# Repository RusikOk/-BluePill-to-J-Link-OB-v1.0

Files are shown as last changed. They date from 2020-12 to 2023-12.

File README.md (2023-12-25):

# programmer-BluePill-to-J-Link-OB-v1.0
успешная попытка создать программатор J-Link OB v1.0 на чипе CS32F103C8T6

в общем валялось у меня пару лет макетка с кристалом CS32F103. использовать в своих разработках я бы такое не стал. а в качестве J-Link OB они зашли на ура.

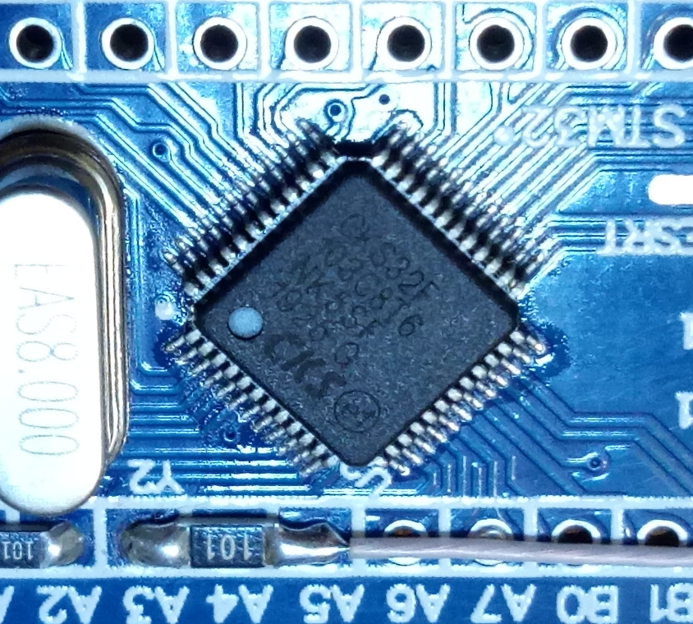
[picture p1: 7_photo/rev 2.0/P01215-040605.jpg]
какашка
 

<h2>REV 1.0</h2>

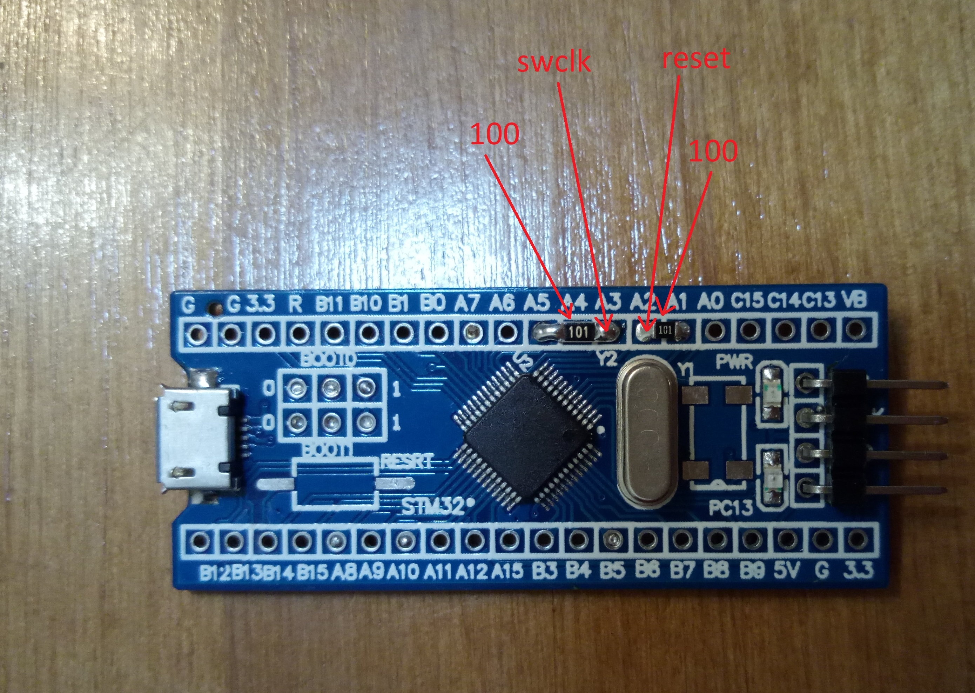
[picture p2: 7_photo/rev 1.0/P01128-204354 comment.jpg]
 
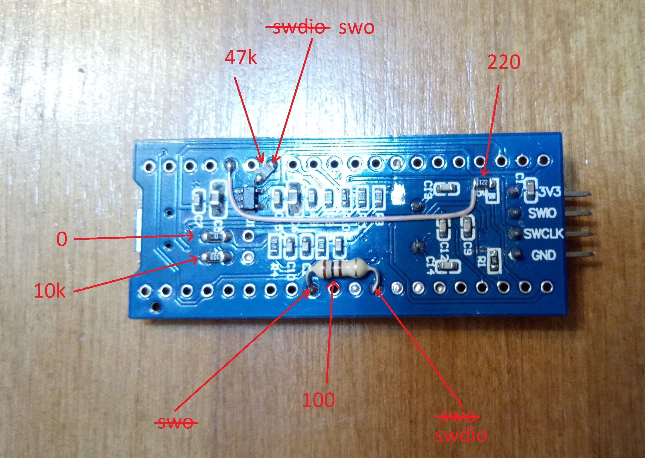
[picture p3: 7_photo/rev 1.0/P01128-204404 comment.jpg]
 
<br>
выявленные недостатки:<br>
- очень бесит когда при обновлении прошивки она тупо слетает в следствии использования мной МК на 64кБ. в идеале нужно использовать МК на 128кБ флешки. хотя если не шляться по чужим компам и постоянно не обновлять библиотеки jLink то жить можно.<br>
- маленькая нагрузочная способность встроенного в BluePill LDO всего на 300мА, что не позволяет запитывать target током больше 250мА.<br>
- при подключении target на горячую проседает питание программатора и он отваливается. приходится перетыкать USB.<br>
<br>
ссылки:<br>
<a href="http://forum.easyelectronics.ru/viewtopic.php?p=649897#p649897">J-Link OB (On-Board)</a><br>

<h2>REV 1.1</h2>

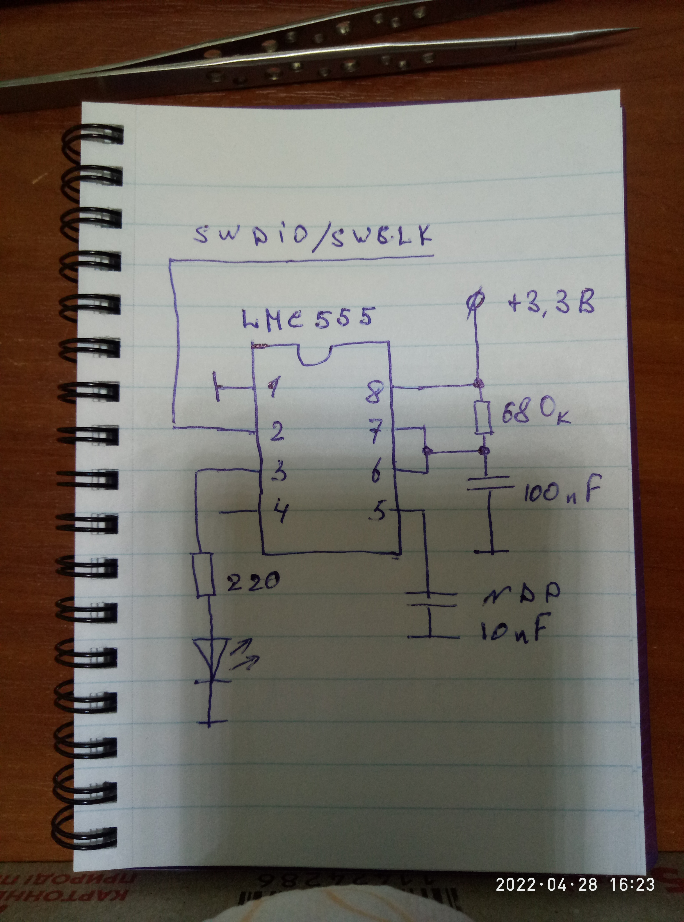
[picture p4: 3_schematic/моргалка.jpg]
schematic

bottom
выявленные недостатки:<br>
- вход таймера нужно было подключать к SW_DIO чтобы при отключенном target светодиод не моргал.<br>

<h2>REV 2.0</h2>

особенностью второй версии программатора является возможность запитки целевой платы током до 1А благодаря применению понижающего DC-DC преобразователя напряжения.<br>
<br>
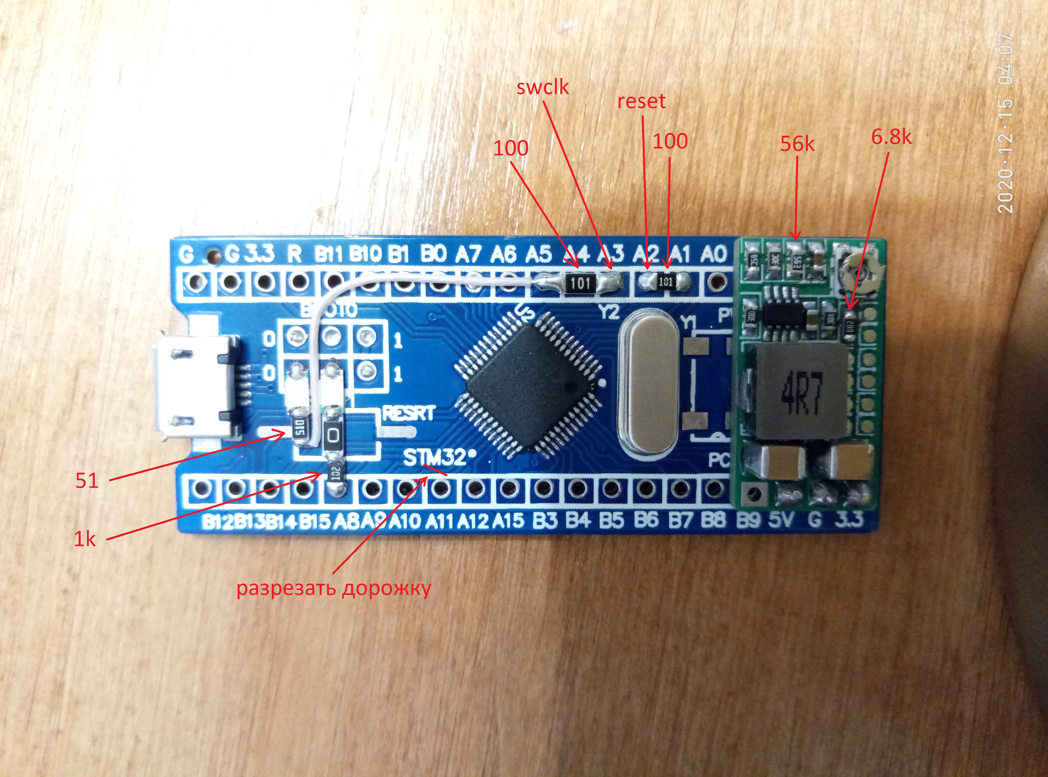
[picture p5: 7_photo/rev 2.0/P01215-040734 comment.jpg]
 
1) проверить все номиналы резисторов на DC-DC, китайцы могут вариировать номиналы<br>
2) не помню перерезана перемычка ADJ с обратной стороны DC-DC или нет. проверить<br>
3) на синий светодиод SW_CLK желательно поставить транзистор в ключевом режиме дабы по минимуму нагружать вывод МК<br>
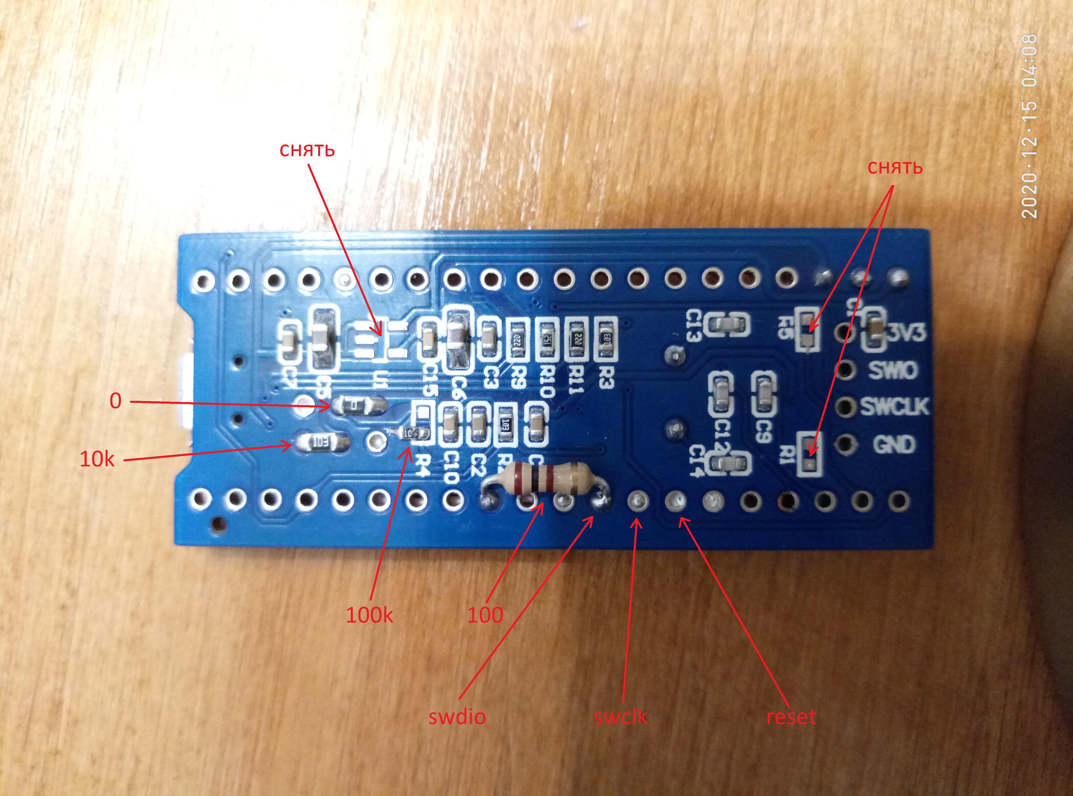
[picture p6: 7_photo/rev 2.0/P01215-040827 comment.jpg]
 
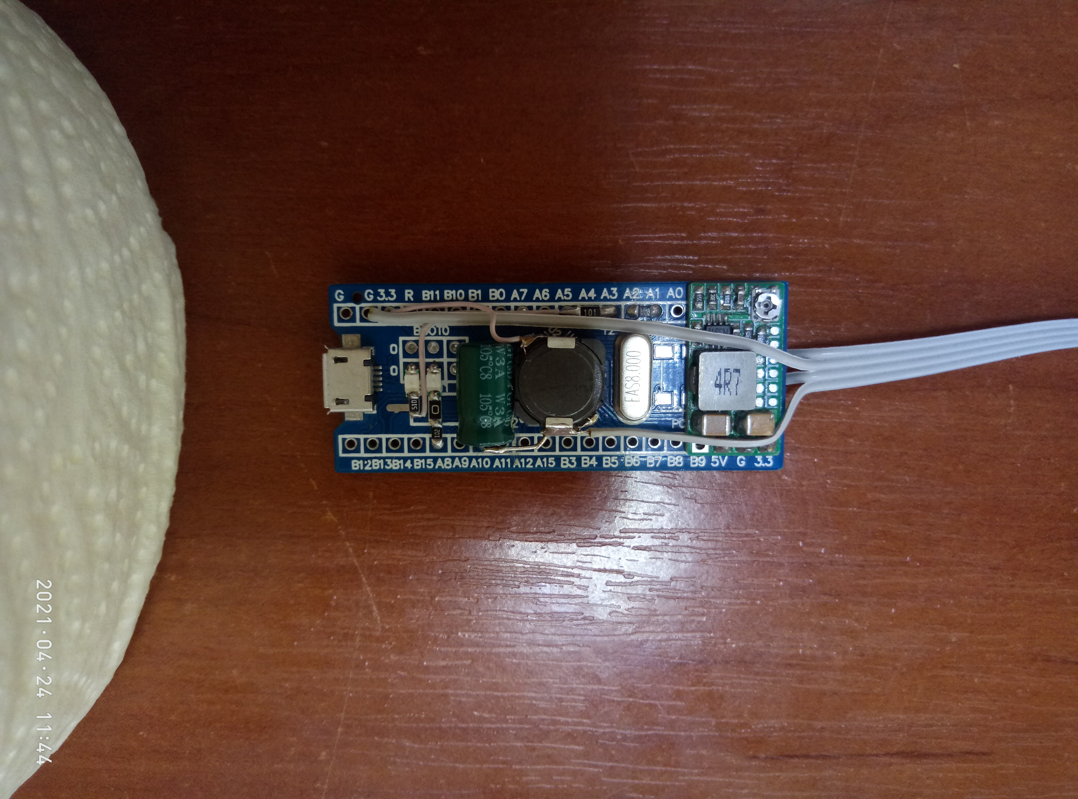
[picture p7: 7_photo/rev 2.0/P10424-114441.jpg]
 
bottom 
<br>
выявленные недостатки:<br>
- очень бесит когда при обновлении прошивки она тупо слетает в следствии использования мной МК на 64кБ. в идеале нужно использовать МК на 128кБ флешки. хотя если не шляться по чужим компам и постоянно не обновлять библиотеки jLink то жить можно.<br>
- оказалась неудачной компоновка светодиодов зеленый (USB) и синий (SW_CLK) сливаются в следствии чего через корпус не видно происходит обмен с target или нет. зеленый светодиод нужно оставить на месте возле разъема USB а синий перенести на противоположную сторону платы. возможно использовать DIP корпус диаметром 3мм.<br>
- на больших скоростях обмена синий светодиод (SW_CLK) очень слабо виден. поэтому как вариант поставить одновибратор на LMC555 таймере для выравнивания длительности свечения светодиода.<br>
<br>
ссылки:<br>
<a href="https://mysensors-rus.github.io/Blue-pill-to-JLink/">Делаем из BluePill пограмматор/отладчик JLink OB-STM32F103</a><br>
<a href="http://forum.easyelectronics.ru/viewtopic.php?p=650368#p650368">J-Link OB (On-Board)</a><br>
<a href="http://easyelectronics.ru/malenkaya-xitrost.html">Маленькая хитрость</a><br>
<a href="http://we.easyelectronics.ru/STM32/cs32f103c8t6-gd32f103cbt6-i-drugie-kitayskie-klony-stm32f103c8t6-i-stm32f030c8t6.html">китайские клоны STM32</a><br>

<h2>BOX</h2>

<a href="https://github.com/RusikOk/-BluePill-to-J-Link-OB-v1.0/blob/main/6_3D%20%D0%BF%D0%B5%D1%87%D0%B0%D1%82%D1%8C/for%20Dobot%20Mooz%202%20-%20PLA.curaprofile">настройки слайсера Ultimaker Cura для генерации G-кода для 3D принтера Dobot Mooz 2</a>

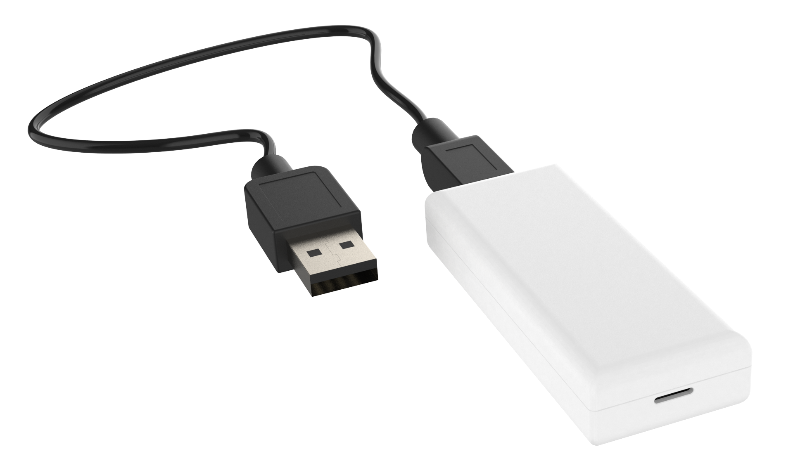
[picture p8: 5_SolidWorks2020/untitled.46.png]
 
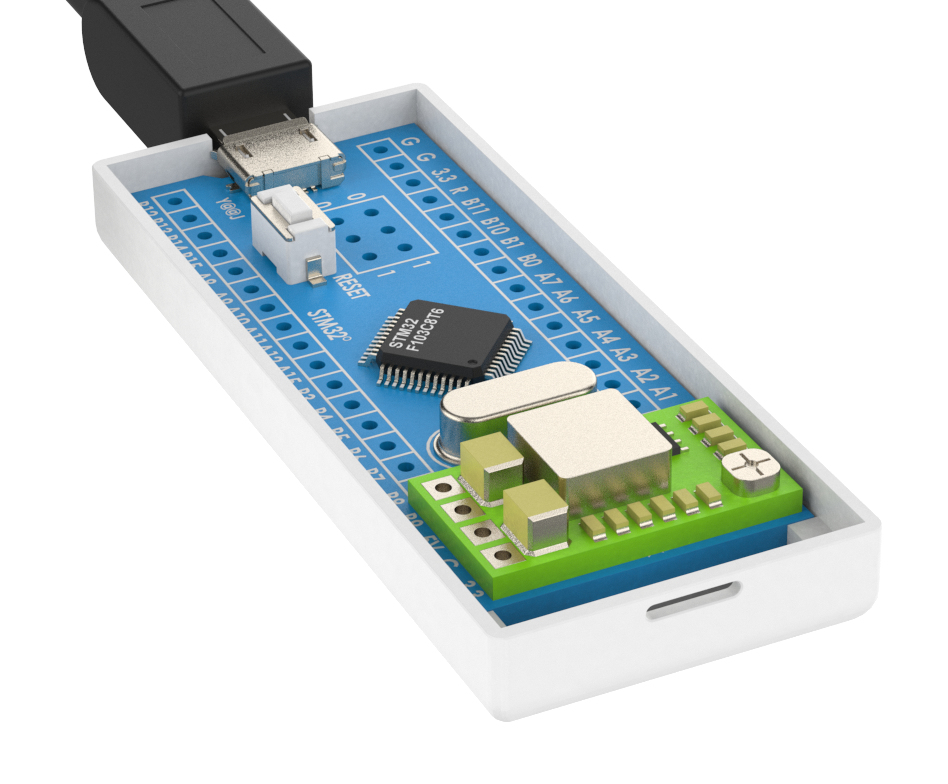
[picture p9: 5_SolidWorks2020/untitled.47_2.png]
 
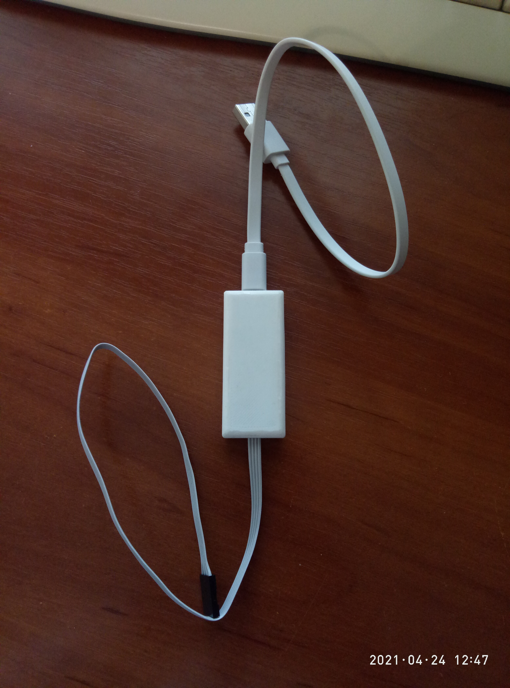
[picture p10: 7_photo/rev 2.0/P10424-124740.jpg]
 
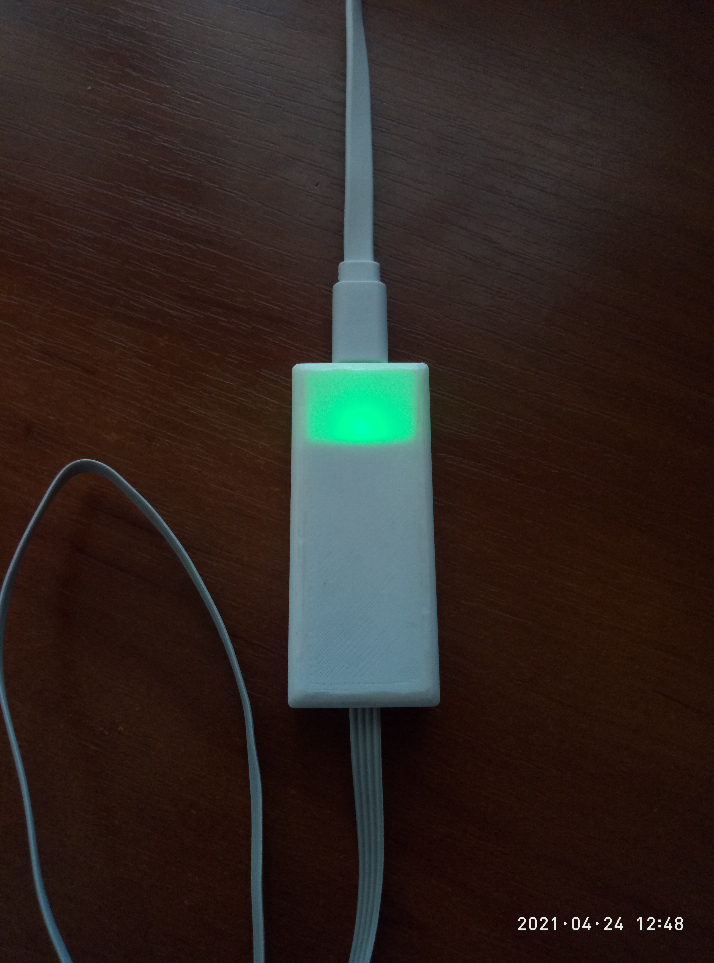
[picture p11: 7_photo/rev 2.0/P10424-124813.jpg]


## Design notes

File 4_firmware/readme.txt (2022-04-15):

последовательность прошивки самого программатора compiled Apr 8 2020 10:10:28 	(НЕ АКТУАЛЬНО)

1) зашить прошивку 1_2019_jlink-obSTM32F103.bin
2) запустить утилиту JLink.exe из старой версии драйверов c:\Program Files (x86)\SEGGER\JLink_V500\
3) установить новый серийный номер коммандой "exec SetSN=20201111"
4) зашить прошивку 2_JLink_OB_STM32F103_V1_compiled_Apr_8_2020.bin

(с) RusikOk 2020-11-29

последовательность прошивки новой версии программатора compiled Feb 2 2021 16:45:54

1) зашить прошивку 3_JLink_OB_STM32F103_V1_compiled Feb 2 2021.bin
2) запустить утилиту JLink.exe из старой версии драйверов c:\Program Files (x86)\SEGGER\JLink_V500\
3) установить новый серийный номер коммандой "exec SetSN=20211111"

(с) RusikOk 2021-04-21

последовательность создания новой версии прошивки программатора для МК CS32F103

1) зашить прошивку 4_JLOB103V1_bootloader.bin
2) подключаем J-Link к компьютеру по USB и запускаем J-Link Commander, а он уже установит актуальную версию прошивки
3) запустить утилиту JLink.exe из старой версии драйверов c:\Program Files (x86)\SEGGER\JLink_V500\
4) установить новый серийный номер коммандой "exec SetSN=20210420"

опять что-то поменялось(

1) зашиваем прошивку загрузчика 4_JLOB103V1_bootloader.hex в контроллер со 128кБ памяти
2) подключаем по USB
3) запускаем самую свежую версию JLink.exe, и обновляем прошивку
4) несколько раз отключаем программатор по USB и обратно включаем
5) подключаемся по SWD к контроллеру с полной прошивкой
6) вычитываем 64кБ (Size 0x10000) и сохраняем в файл
7) записываем с файла в CS32F103
8) копируем 8 байт с адреса 0x08004000 в буффер обмена и вставляем на адрес 0x08000000
9) устанавливать новый серийник ЗАПРЕЩЕНО!!! пусть остается -1
10) готовая прошивка от 2021-10-27 с названием 5_2021-10-27.hex

(с) RusikOk 2021-10-27

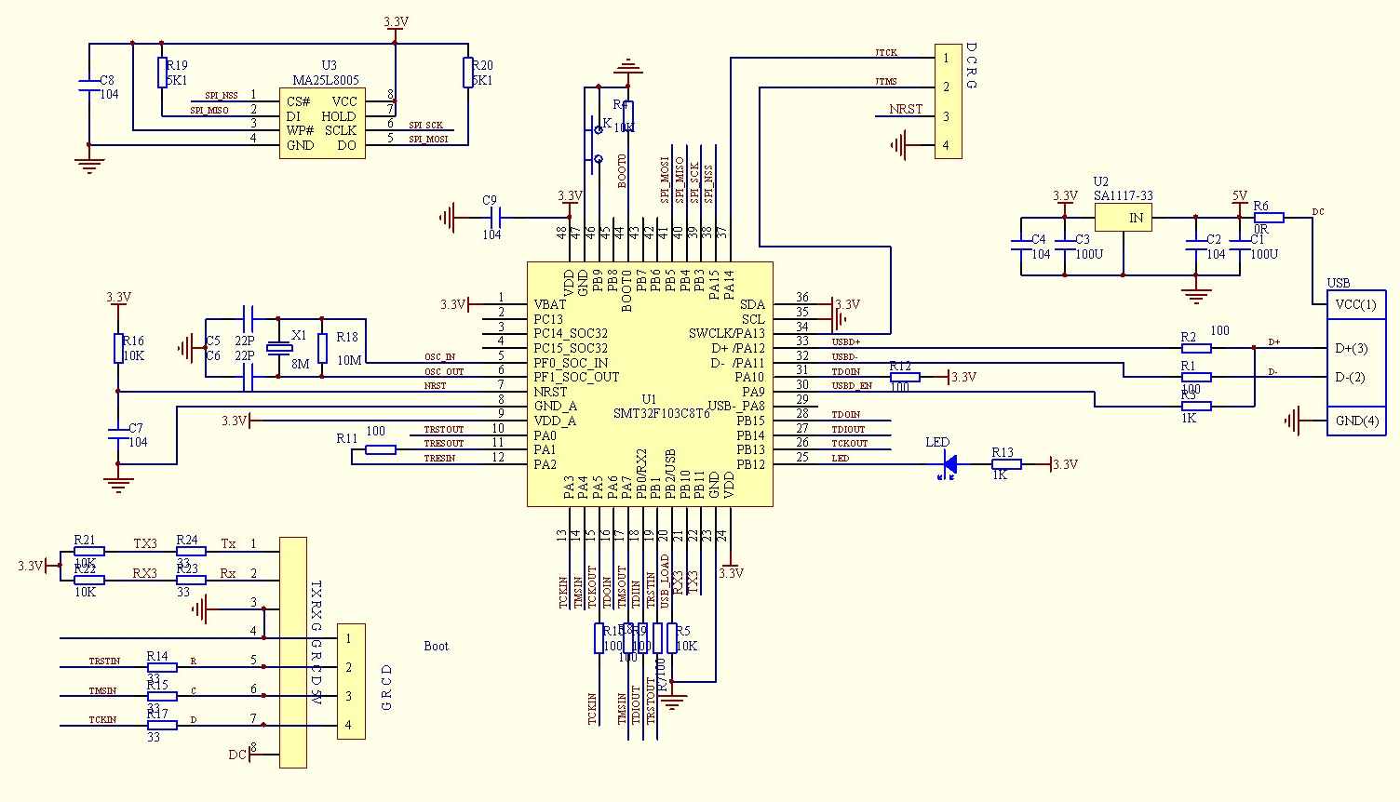
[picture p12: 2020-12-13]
3_schematic/2019_jlink-obSTM32F103_не правильная.jpg

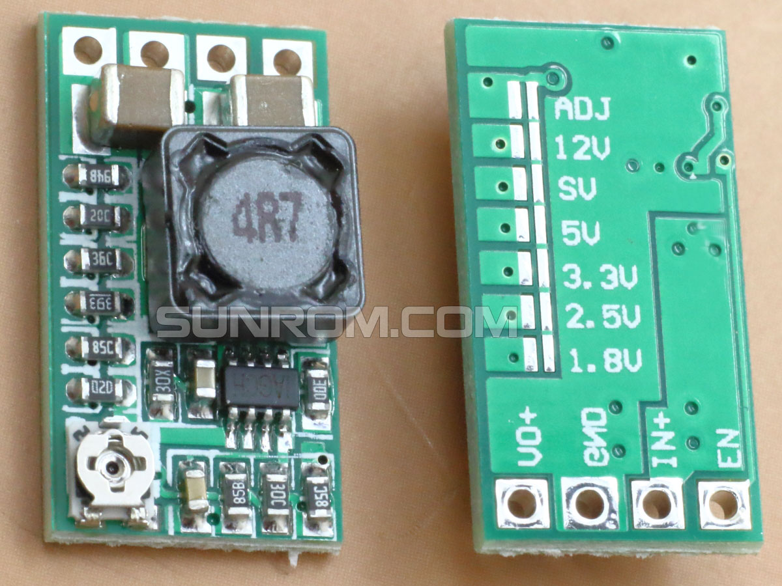
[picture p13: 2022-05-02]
2_datasheet/MP2315S.jpg

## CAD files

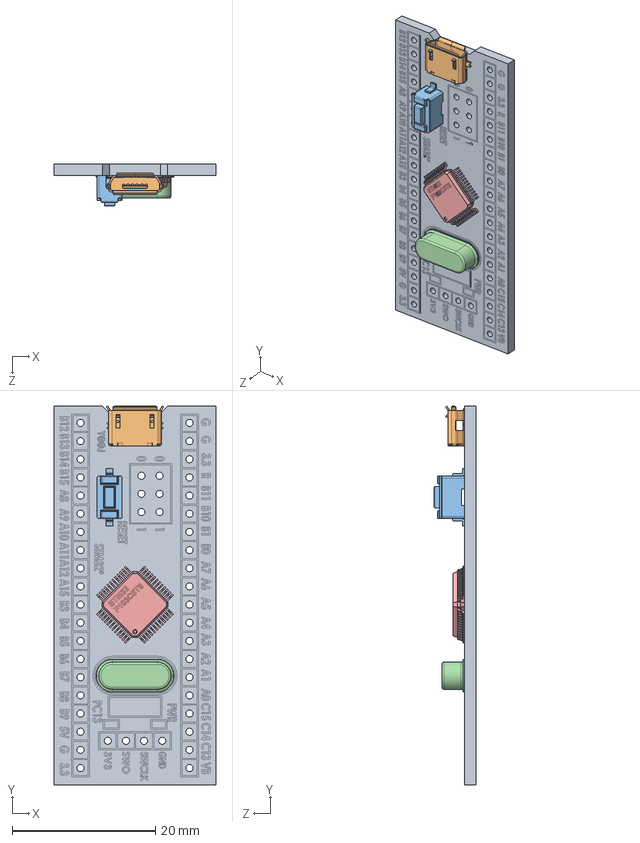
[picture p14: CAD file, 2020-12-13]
5_SolidWorks2020/2_BluePill/BluePill.SLDASM
22.6 x 53.0 x 5.90 mm
BluePill_Board
USB_Socket
Pushbutton
Quartz_1___ _________
STM32F103C8T6

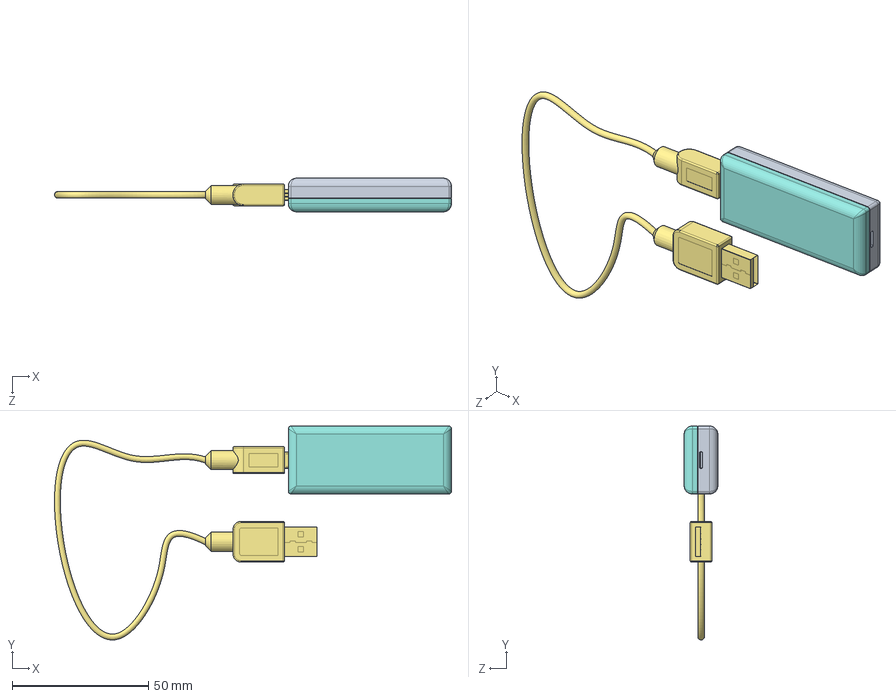
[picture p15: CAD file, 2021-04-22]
5_SolidWorks2020/Сборка.SLDASM
145.9 x 78.6 x 12.4 mm
основание
BluePill_Board
USB_Socket
Pushbutton
Quartz_1___ _________
STM32F103C8T6
microUSB_cabel
крышка
05KJ_Mini_PCB_Regulator
CDRH104RNP
Cap electro 6_3x11x2_5mm

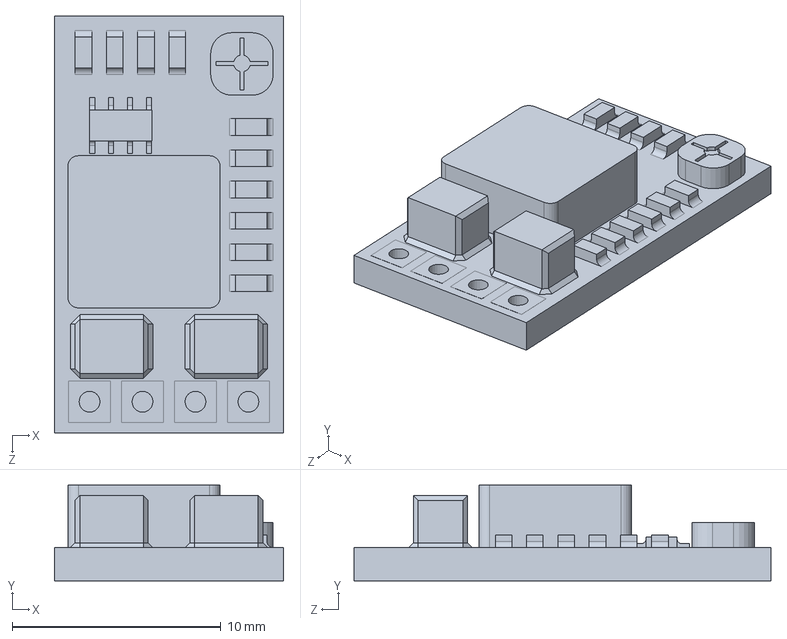
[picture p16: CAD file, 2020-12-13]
5_SolidWorks2020/step-down-converter-1.snapshot.5/05KJ_Mini_PCB_Regulator.SLDPRT
11.0 x 4.60 x 20.0 mm

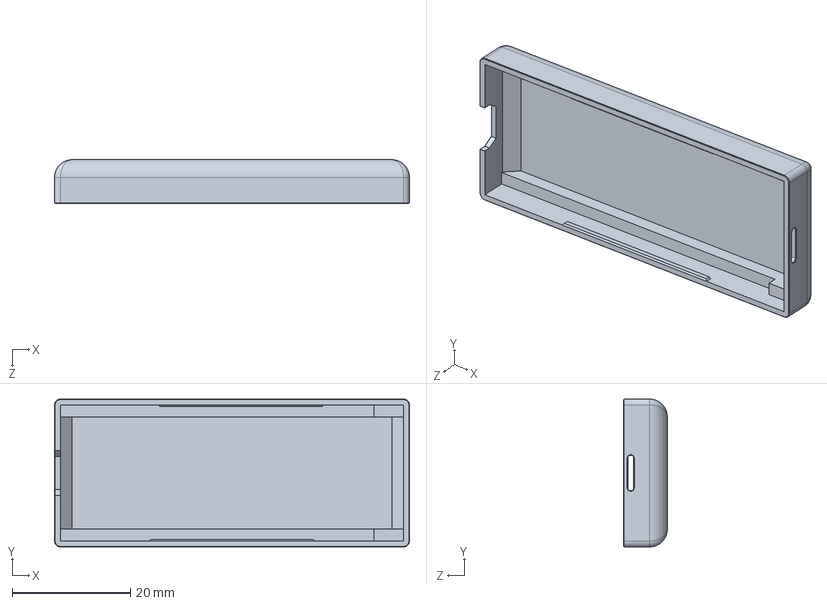
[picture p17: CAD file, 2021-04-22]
5_SolidWorks2020/основание.SLDPRT
60.0 x 25.0 x 7.40 mm

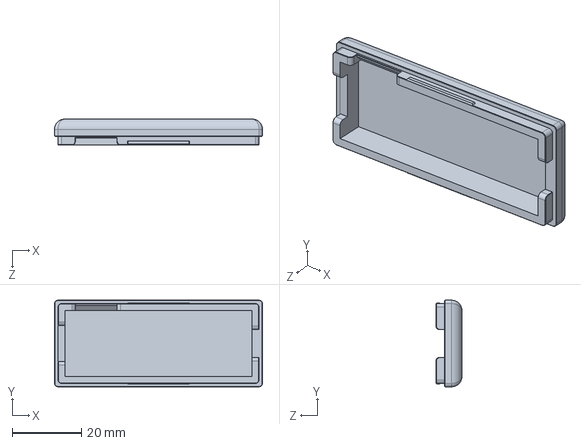
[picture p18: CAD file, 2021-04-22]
5_SolidWorks2020/крышка.SLDPRT
60.0 x 25.0 x 7.50 mm

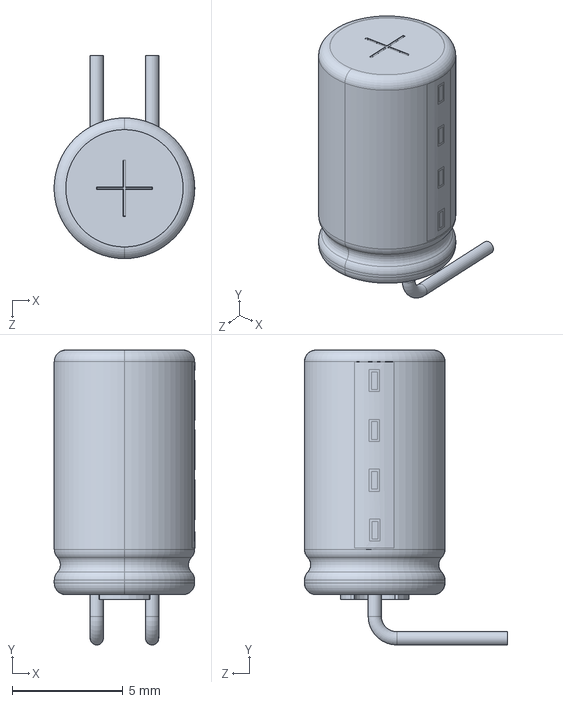
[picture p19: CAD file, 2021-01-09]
5_SolidWorks2020/Cap electro 6_3x11x2_5mm.sldprt
6.35 x 13.3 x 9.18 mm

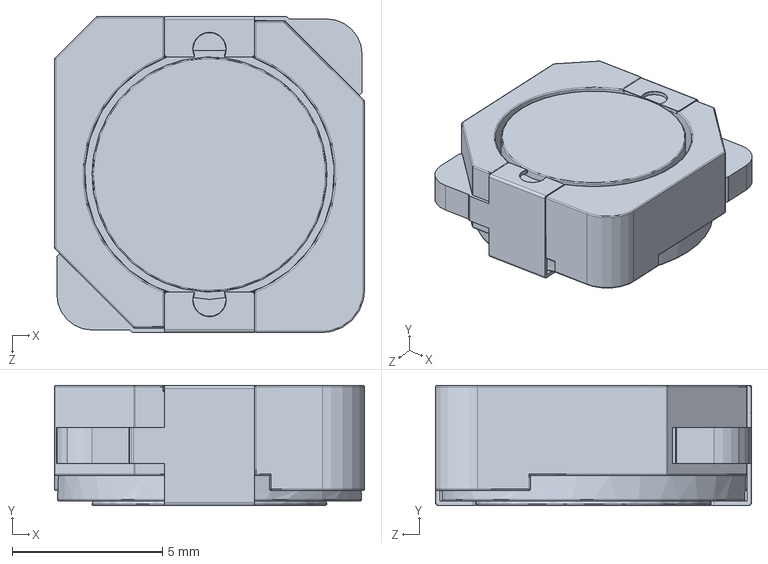
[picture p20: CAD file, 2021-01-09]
5_SolidWorks2020/CDRH104RNP.SLDPRT
10.3 x 4.00 x 10.5 mm

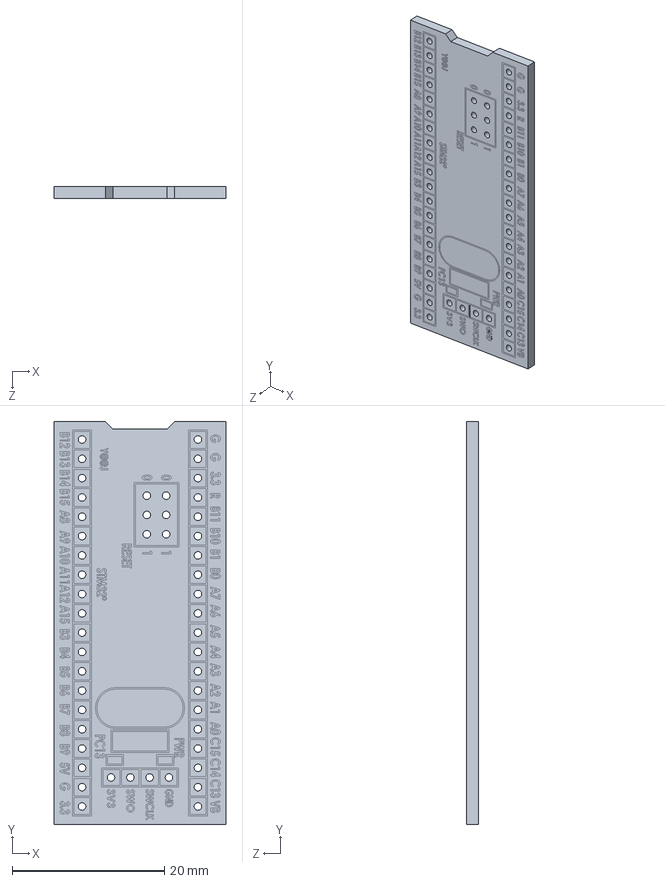
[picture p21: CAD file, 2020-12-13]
5_SolidWorks2020/2_BluePill/BluePill_Board.SLDPRT
22.6 x 53.0 x 1.61 mm

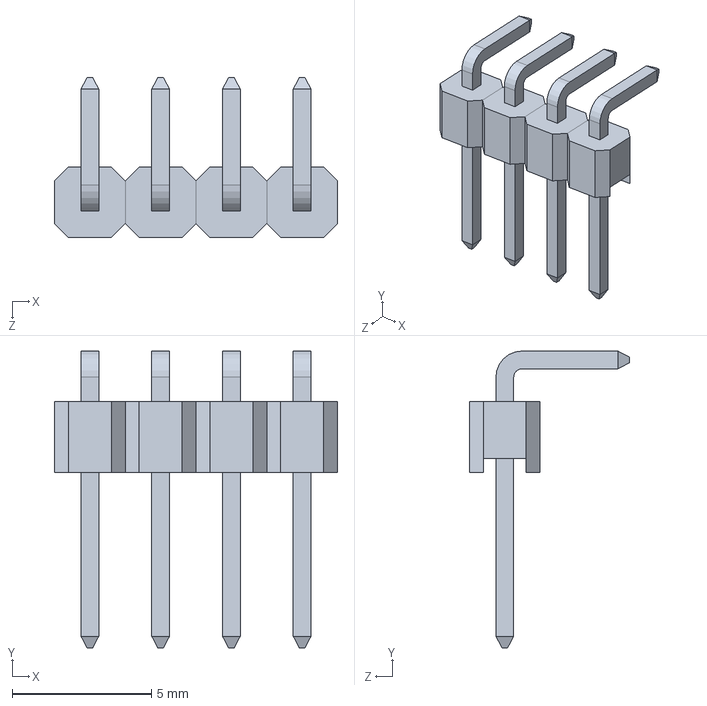
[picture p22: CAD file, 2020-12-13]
5_SolidWorks2020/PLSR-04-1-2.54mm.SLDPRT
10.2 x 10.7 x 5.75 mm

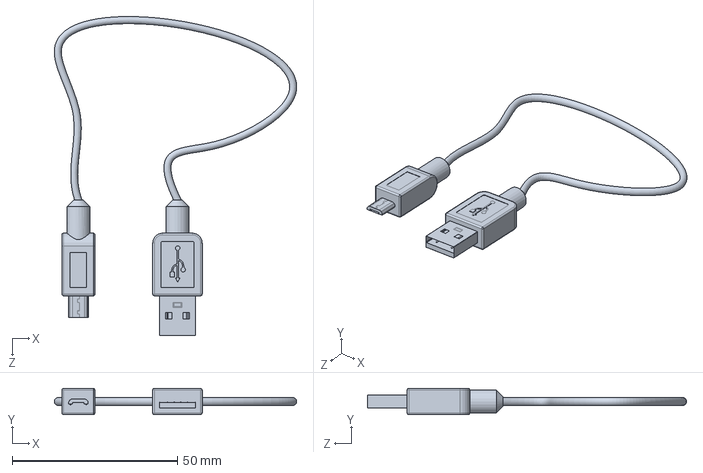
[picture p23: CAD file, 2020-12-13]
5_SolidWorks2020/microUSB_cabel.SLDPRT
73.4 x 8.00 x 96.6 mm

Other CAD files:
5_SolidWorks2020/2_BluePill/Pushbutton.SLDPRT
5_SolidWorks2020/2_BluePill/USB_Socket.SLDPRT
5_SolidWorks2020/2_BluePill/STM32F103C8T6.SLDPRT
5_SolidWorks2020/2_BluePill/Quartz_1___ _________.SLDPRT

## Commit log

2020-12-13 добавил описание на фото
2020-12-13 дополнил описание на фото
2020-12-13 Create README.md
    написал минимальное описание
2020-12-13 немного лохонулся
2020-12-15 немного фоточек
2020-12-15 дополнил описание по v 2.0
2020-12-20 добавил ссылку на форум
2021-01-09 добавил фильтр по питанию на модель
    [CDRH104RNP.SLDPRT, Cap electro 6_3x11x2_5mm.sldprt, Сборка.SLDASM]
2021-04-21 обновил прошивку + мелочи
    1) обновил прошивку до версии от Feb 2 2021 16:45:54
    2) обновил рендеры корпуса
    3) добавил настройки для 3D принтера
    4) уточнил размеры верхней крышки корпуса
    [крышка.SLDPRT]
2021-04-22 переработал защелки в корпусе
    [Сборка.SLDASM, крышка.SLDPRT, основание.SLDPRT]
2021-04-24 наконец-то собрал
    1) исправил подписи в rev 1.0
    2) подписал платы rev 2.0
    3) напечатал удовлетворительный корпус
    4) собрал все и проверил - работает
2021-10-26 обновление
    отправил комп в спящий режим когда была запущена отладка. и прошивка программатора слетела. решил обновить драйвера jLink и началось...
2021-11-16 мелкие дополнения
    проверил максимальный отдаваемый ток преобразователем напряжения питания
2021-12-19 поменял структуру каталогов
    [05KJ_Mini_PCB_Regulator.SLDPRT, BluePill.SLDASM, BluePill_Board.SLDPRT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]
2021-12-19 описал недостатки эксплуатации
    1) подправил ссылки на документы со структуры каталогов
    2) описал недостатки эксплуатации разных версий
2021-12-19 правки
2021-12-19 идеально
2022-04-15 уточнение
2022-04-28 свистелки и перделки
    откатал моргалку на 555 таймере. для нормального отображения активности на линии данных шины SWD
2022-05-02 положил описание на DC/DC
2022-08-18 описал моргалку активности обмена с target
2023-12-25 переименовал каталоги
2023-12-25 поправил описание
2024-11-05 бекап
